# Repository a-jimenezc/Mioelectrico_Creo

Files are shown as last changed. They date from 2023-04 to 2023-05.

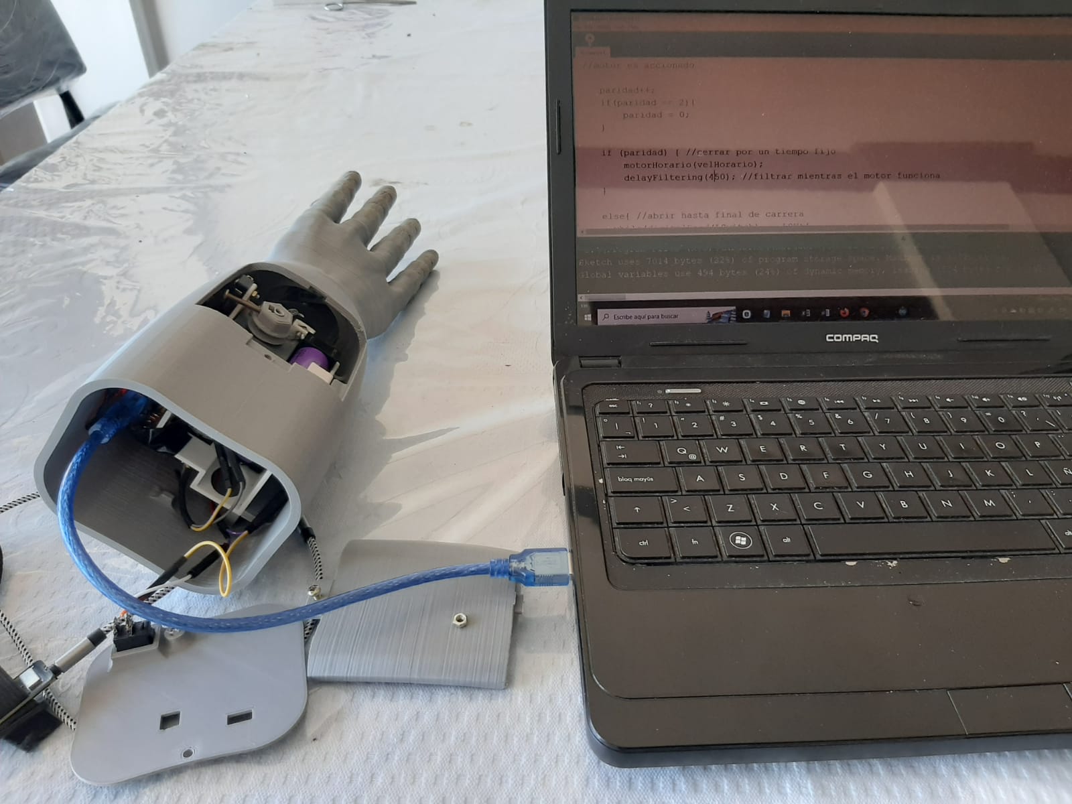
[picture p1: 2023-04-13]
Multimedia/fotos/foto_1.jpeg

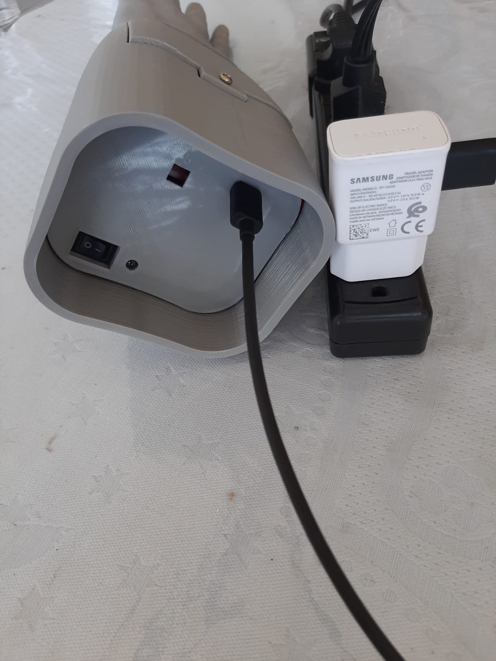
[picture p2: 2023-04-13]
Multimedia/fotos/foto_2.jpeg

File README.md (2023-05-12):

# Proyecto Mioeléctrico

## Descripción
Este proyecto consiste en el desarrollo de una prótesis mioeléctrica para personas con extremidades superiores amputadas. La prótesis utiliza la señal mioeléctrica generada por un músculo para activar un motor que controla la mano de la prótesis. Además, se utiliza una impresora 3D para fabricar las piezas de la prótesis en PLA. 

## Requisitos
- Sensor de señal mioeléctrica DF-Robot
- Microcontrolador Arduino Nano
- Diferentes componenetes electrónicos (ver lista)
- Motor para la mano de la prótesis
- Impresora 3D y material PLA

## Funcionamiento
- El sensor captura la señal mioeléctrica del músculo y la envía al Arduino Nano.
- El Arduino Nano procesa la señal en tiempo real utilizando un algoritmo que incluye un filtro digital y una función de activación.
- La función de activación identifica la orden del usuario para activar la prótesis. La orden se envía mediante una contracción brusca del músculo.
- El motor se controla en lazo abierto, alternando el sentido de giro para abrir y cerrar la mano de la prótesis.
- El movimiento del motor se transmite a la mano de la prótesis mediante un eslabón triangular de transmisión.

## Próximos pasos
Actualmente, se está finalizando el desarrollo de esta segunda versión de la prótesis. Es necesario realizar pruebas en pacientes para evaluar el funcionamiento de la misma en condiciones reales. Adicionalmente, se requiere trabajar en la electrónica y el mecanismo de control de la prótesis. 

Revisar la carpeta documentación para más información.

## Autores
Antonio Jiménez Caballero

Otros autores....

## Licencia
Por definir.

## Contribuciones
Luis Villafani
Otros contribuyentes....

Se aceptan contribuciones al proyecto. Por favor, crea un "pull request" con tus propuestas.

## Contacto
Por definir.

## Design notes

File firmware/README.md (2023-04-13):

## Control Mioeléctrico para Control de Motores utilizando Arduino

Este código de Arduino está diseñado para habilitar el control mioeléctrico de un motor utilizando un sensor EMG analógico. El código utiliza la biblioteca "movingAvg" para calcular promedios móviles y la biblioteca "EMGFilters" para filtrar las señales EMG. El código está destinado a ser utilizado con un sensor EMG analógico, como el sensor "Analog_EMG_Sensor_by_OYMotion_SKU_SEN0240".

Para usar este código, sigue los siguientes pasos:

### Paso 1: Configuración del Hardware

Conecta el sensor EMG analógico a la placa de Arduino. El cable de señal del sensor debe conectarse al pin A7 de Arduino (o cambia el valor de "SensorEmgInputPin" al número de pin apropiado en el código).
Conecta el motor a los pines apropiados de Arduino para el control del motor. El motor se controla mediante señales PWM, así que asegúrate de conectarlo a los pines apropiados con capacidad de PWM (por ejemplo, D9 y D10).

### Paso 2: Configuración del Software

Instala las bibliotecas "movingAvg" y "EMGFilters" en tu entorno de desarrollo de Arduino. Estas bibliotecas son necesarias para que el código funcione correctamente.
Copia y pega el código proporcionado en tu entorno de desarrollo de Arduino.

### Paso 3: Configuración

Configura los parámetros en el código para adaptarlos a tus requisitos específicos. Por ejemplo, puedes ajustar la frecuencia de muestreo, la frecuencia de rechazo, el intervalo de muestreo, los parámetros de control del motor y los valores de umbral según tus necesidades.
Asegúrate de leer y entender la documentación de las bibliotecas "movingAvg" y "EMGFilters" para configurarlas y utilizarlas correctamente en tu código.

### Paso 4: Carga y Ejecución

Carga el código en tu placa de Arduino.
Abre el Monitor Serie en tu entorno de desarrollo de Arduino para ver la salida del código.
Enciende tu motor y tu sensor EMG.
El código realizará el control mioeléctrico del motor basado en las señales EMG filtradas y los valores de umbral calculados durante la ejecución.

Nota: Es importante calibrar adecuadamente los valores de umbral para tu configuración específica para asegurar un control mioeléctrico confiable y preciso del motor. Experimenta con diferentes valores de umbral y parámetros de control del motor para lograr el rendimiento deseado.

Para obtener más información sobre el código, consulta los comentarios en el código y la documentación de las bibliotecas "movingAvg" y "EMGFilters". Además, consulta la documentación del sensor EMG analógico utilizado en tu configuración para obtener más detalles sobre su uso y calibración.

Descargo de responsabilidad: Este código se proporciona tal cual y puede requerir más modificaciones y pruebas para tu aplicación específica. Úsalo bajo tu propio riesgo y siempre sigue las precauciones de seguridad apropiadas al trabajar con motores y circuitos eléctricos.

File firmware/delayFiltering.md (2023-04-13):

La función *delay_filtering* permite leer pulsos enviados por el músculo. Además, permite adaptar en tiempo real el threshold de activación del motor según las amplitud de la señal.

Matemáticamente, la función juega con el delay intrínseco del filtro *moving average* para ser sensible únicamente a los cambios bruscos en la señal. Esto permite que el motor pueda ser controlado con pulsos del músculo, a la vez que se evita el ruido.

    void delayFiltering(int milliseconds){
      int milliseconds_2 = (1000/sample_interval)*milliseconds; //float to int
      for(int i=0; i < milliseconds_2; i++){//delay filtrando
           int Value= analogRead(SensorEmgInputPin);
           int DataAfterFilter = myFilter.update(Value);
           unsigned  long envlope = sq(DataAfterFilter);
           unsigned  long mov_avg = movAvg_myo.reading(envlope);

           if(Threshold < 60){Threshold = aux_trh.reading(trsh_60);} //treshold dinámico
           else if(Threshold < prim_int ){Threshold = aux_trh.reading(mov_avg*(1+(funParametro_1-pow(Threshold,1/30))));}
           else if(Threshold < seg_int ){Threshold = aux_trh.reading(mov_avg*(1+(funParametro_2-pow(Threshold,1/30))));} 
           else{Threshold = aux_trh.reading(mov_avg*(1+(1.2-pow(Threshold,1/30))));}

           Serial.print("absuared Data: ");
           Serial.println(mov_avg);
           Serial.print("threshold: ");
           Serial.println(Threshold);
       delayMicroseconds(sample_interval);//debe coincidir con SAMPLE_FREQ
      }   
    }

Descripción:

La función "delayFiltering" realiza el filtrado de las señales EMG y la actualización del umbral dinámico de manera retardada durante un tiempo especificado en milisegundos. A continuación se describen los pasos principales del proceso:

Conversión de milisegundos a muestras: Se calcula el número de muestras necesarias para el retardo, multiplicando el tiempo en milisegundos por la frecuencia de muestreo inversa en segundos (1000/sample_interval), donde "sample_interval" es el intervalo de muestreo de las señales EMG en microsegundos.

Bucle de filtrado: Se inicia un bucle que se ejecuta tantas veces como el número de muestras calculado en el paso anterior. Dentro del bucle, se realiza lo siguiente:
a. Lectura del valor del sensor EMG: Se lee el valor analógico del pin del sensor EMG utilizando la función "analogRead" y se almacena en la variable "Value".
b. Filtrado de la señal EMG: Se aplica el filtro de EMG previamente configurado utilizando la función "update" de la instancia "myFilter" y se obtiene el valor filtrado en la variable "DataAfterFilter".
c. Cálculo del valor del umbral dinámico: Se calcula el valor del umbral dinámico en función de los parámetros de control y el valor filtrado de la señal EMG. Dependiendo del valor actual del umbral, se utilizan diferentes ecuaciones para calcular el nuevo valor del umbral. Los cálculos se realizan utilizando las funciones "reading" de las instancias "aux_trh", "movAvg_myo" y las operaciones matemáticas como potenciación y raíz. El resultado se almacena en la variable "Threshold".
d. Impresión de valores: Se imprimen en el Monitor Serie los valores del valor absoluto del promedio móvil de la señal EMG (mov_avg) y el umbral dinámico calculado (Threshold) para fines de depuración.
e. Retardo: Se espera un tiempo equivalente al intervalo de muestreo (sample_interval) utilizando la función "delayMicroseconds".

Finalización del bucle: Una vez que se completan todas las iteraciones del bucle, la función "delayFiltering" finaliza.

Es importante tener en cuenta que el valor del umbral dinámico se actualiza en función de los parámetros de control y los valores filtrados de la señal EMG durante el retardo especificado, lo que permite adaptar el umbral a los cambios en la señal EMG en tiempo real.

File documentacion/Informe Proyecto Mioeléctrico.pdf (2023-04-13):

Informe Proyecto Mioeléctrico

Ing. Antonio Jimenez Caballero

### 1. Introducción

Las prótesis funcionales de extremidades superiores presentan una solución para las personas que no disponen de estos miembros. Las prótesis que están siendo actualmente comercializadas en Creotec presentan una construcción mecánica simple pero robusta. La estructura se fabrica con tecnología aditiva y se utiliza un mecanismo de accionamiento que hace uso de hilos, ligas y del principio de palanca. Con esto se logra aprovechar el movimiento de la articulación del codo para lograr abrir y cerrar la mano de la prótesis. Si bien simple y robusta en su construcción, estas prótesis solo pueden ser usadas si es posible hacer uso de la articulación del codo. En los casos donde se tiene el muñón del antebrazo muy pegado al codo o donde solo se disponga del brazo se necesita de otro tipo de prótesis. En este contexto es donde se presenta una prótesis mioeléctrica que hace uso de un motor para accionar la mano de la prótesis. Mediante la lectura de la señal mioeléctrica generada por un músculo, un algoritmo se encarga de activar un motor dc alimentado por baterías el cuál acciona la mano de la prótesis a través de hilos. Adicionalmente, se consigue que el cierre de la mano se adapte a la forma del objeto mediante el uso de un eslabón triangular de transmisión. Actualmente, se está terminando el desarrollo de una segunda versión de esta prótesis mioeléctrica con miras a empezar a hacer pruebas en pacientes.

### 2. Marco teórico

a. Señal electromiografía
Una señal mioeléctrica es la diferencia de potencial generada por los músculos cuando estos se contraen. Las señales EMG tienen una frecuencia que oscila entre 50 y 150 Hz y una amplitud que va desde los μV hasta los 10 mV. Para capturar esta señal se hace uso de electrodos. Estos pueden ser de diversos tipos y el que se utiliza en este proyecto es el electrodo seco de superficie. Estos son electrodos no invasivos que pueden ser montados sobre la misma prótesis y ofrecen la mayor comodidad para su uso continuo. Sin embargo, la calidad de la lectura va a depender del correcto posicionamiento del sensor y de las propiedades conductivas de la piel.

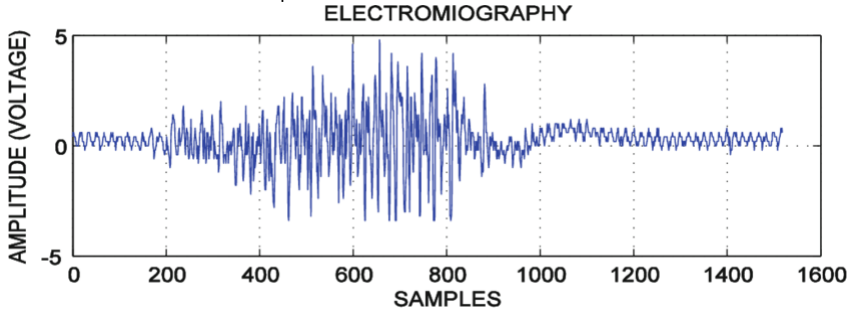
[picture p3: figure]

Figura 1: Señal Mioeléctrica (Vicario)

b. Impresión en 3d
Se utiliza tecnología de fabricación aditiva para la elaboración de la prótesis. En específico, se utiliza modelado por deposición fundida (FDM) de plástico. El plástico utilizado es PLA (poliácido láctico), el cuál es bio-compatible. El uso de esta tecnología permite la fabricación de piezas complejas a bajo costo. Esto es ideal para prótesis personalizadas, cuya fabricación no sería posible mediante otros métodos.

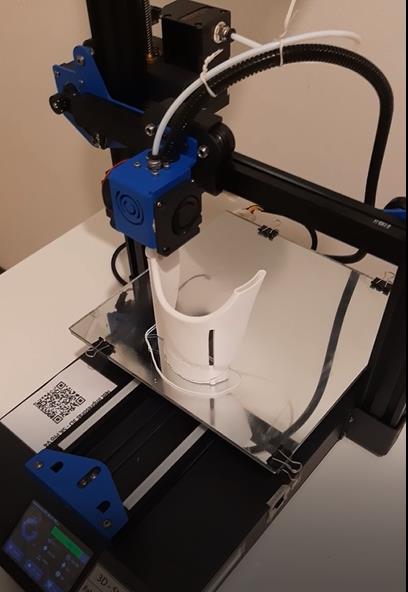
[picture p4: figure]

Figura 2: Impresión de Prótesis

### 3. Prótesis mioeléctrica

La prótesis mioeléctrica que se ha desarrollado hace uso del sensor comercializado por DF-Robot el cual integra un filtro analógico y provee las librerías para un filtro digital

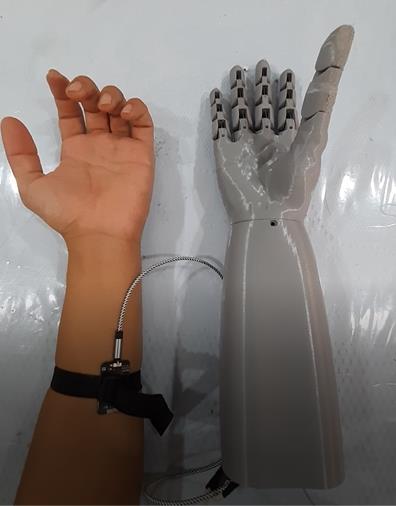
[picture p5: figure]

Figura 3: Prótesis Mioeléctrica

La señal recibida a través de este sensor es enviada al microcontrolador. En este caso se utiliza un ATmega328P el cual viene integrado en el Arduino Nano. El microcontrolador procesa la información recibida en tiempo real mediante la ejecución de un algoritmo. Este consta de un filtro digital, una función de activación y el control del motor. La función de activación es la que permite separar las diferentes señales del músculo de la orden consciente enviada con el propósito de activar la prótesis. La forma en que la prótesis es activada es mediante un pulso de alta intensidad creada por el músculo, el cual se logra mediante una contracción brusca del dicho músculo. La función hace uso de la diferencia del delay de dos filtros de media variable (Moving Average) para capturar la presencia del pulso. Una vez este es identificado se da la orden para que el motor funcione. El sentido de giro del motor alternará entre horario y antihorario con cada orden, lo cual corresponde con abrir y cerrar respectivamente. La orden de cerrar hace que el motor funcione por un tiempo fijo en sentido antihorario y la orden de abrir consiste en el motor funcionando en sentido apuesto hasta topar con un final de carrera, el cual coincide con la posición de mano abierta. Cabe mencionar que este es un mecanismo de control del motor de lazo abierto.

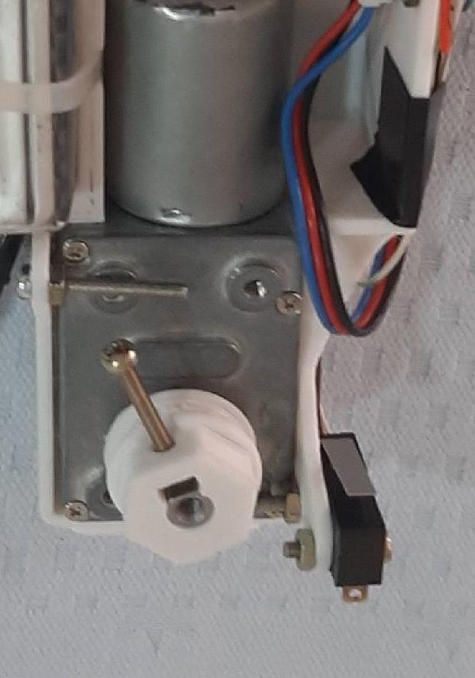
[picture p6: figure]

Figura 4: Motor con el Tambor Unido al eje

El motor acciona el hilo mediante un tambor, el movimiento de este hilo se transmite a otros cinco hilos, uno por dedo, a través de un eslabón triangular. Este eslabón permite que los hilos se deslicen uno respecto del otro, permitiendo que el cierre de los dedos se adapte a la forma del objeto que se está agarrando.

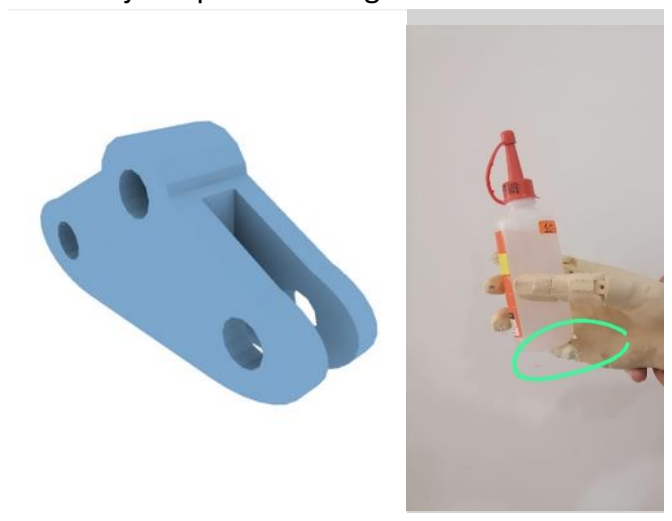
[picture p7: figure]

Figura 5: Eslabón Triangular y Agarre Adaptativo (SkipMeetze)

El motor es alimentado con un par de baterías Li-ion 18650 dispuestas en paralelo. Junto con las baterías se tiene sus protecciones (BMS), su módulo de carga (micro-USB) y su elevador de tensión (Step-Up).

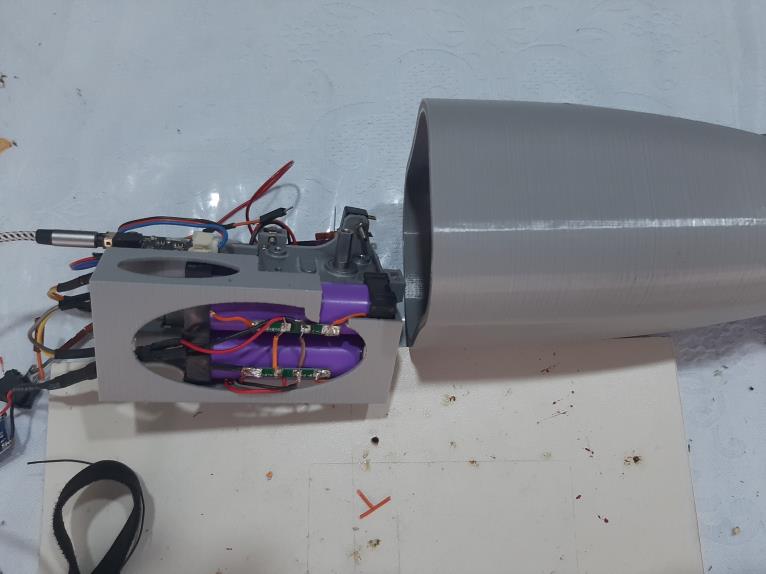
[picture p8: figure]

Figura 6: Baterías en la Estructura Extraíble

Todos los componentes están dispuestos en un chasis extraíble, lo cual permite que toda la electrónica pueda ser ensamblado fuera de la prótesis. Una vez todo este en su lugar, esta es introducida en el interior de la prótesis y se procede a ajustar la tensión del hilo principal a través de una abertura dejada para tal propósito.

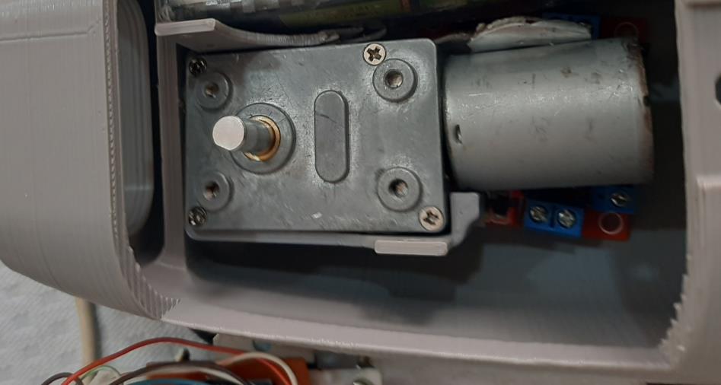
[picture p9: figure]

Figura 7: Estructura Extraíble Instalada en el Antebrazo

### 4. Conclusiones

La prótesis mioeléctrica presentada puede ser usada por personas que no presenten la articulación del codo y, por lo tanto, se presenta como una solución al problema planteado. Al usar elementos electrónicos de uso común y disponibles para su compra en Bolivia, esta puede ser construida a muy bajo costo comparada con otras prótesis comerciales de su tipo. Sin embargo, se pueden evidenciar mejoras a realizar. La primera es la posibilidad de extraer más información de la señal del sensor mioeléctrico. Esto se puede realizar mediante el uso de técnicas de procesamiento digital de señales para extraer características de la señal y lograr más estados que solo abrir o cerrar. En particular, se desea que la intensidad del cierre se proporcional a la intensidad de la acción del músculo, esto con el fin de dar mayor control a la persona sobre los objetos que se están agarrando. Un segundo elemento a mejorar el añadir un control de lazo cerrado al motor. Esto permitiría mayor precisión en el agarre de objetos. Un tercer elemento a mejorar es la implementación de un PCB que integre toda la electrónica. Si bien el uso de módulos electrónicos comerciales es ventajoso en términos de hacer prototipos, el elevado volumen de cables es un problema. Finalmente, es necesario estudiar el lugar idóneo para posicionar el sensor, ya que estos deber ir sobre músculos óptimos para la tarea.

### 5. Referencias

SkipMeetze. Adaptive grip mechanism for Prosthetic hand. National Institutes of Health. Retrieved October 24, 2022, from https://3dprint.nih.gov/discover/3dpx-001001

Vicario Vazquez, S. A., Oubram, O., &amp; Ali, B. (2018). Intelligent recognition system of myoelectric signals of Human Hand Movement. Intelligent Computing Systems, 97–112. https://doi.org/10.1007/978-3-319-76261-6_8

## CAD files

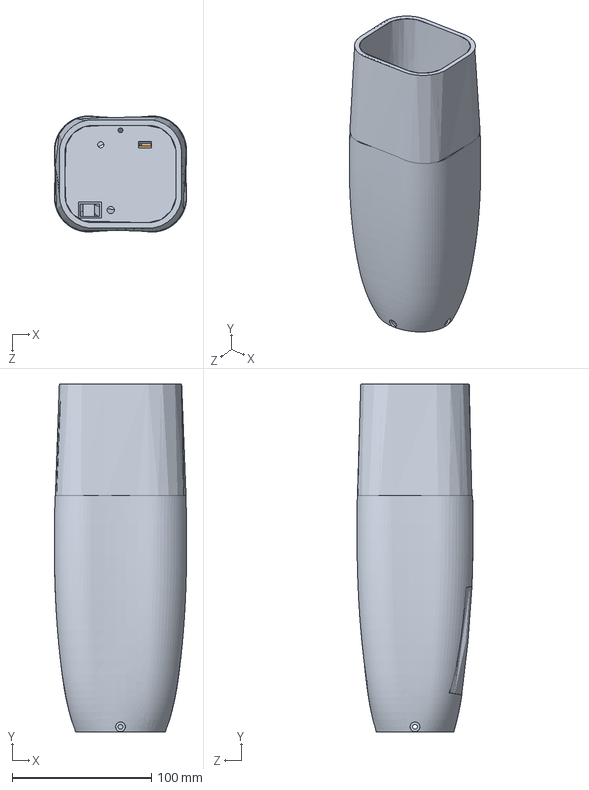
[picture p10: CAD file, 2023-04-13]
SW_CAD_files/AssemV6/Assem1.SLDASM
95.2 x 250.2 x 83.5 mm
AntebrazoV6
chasis3V1
switchV2

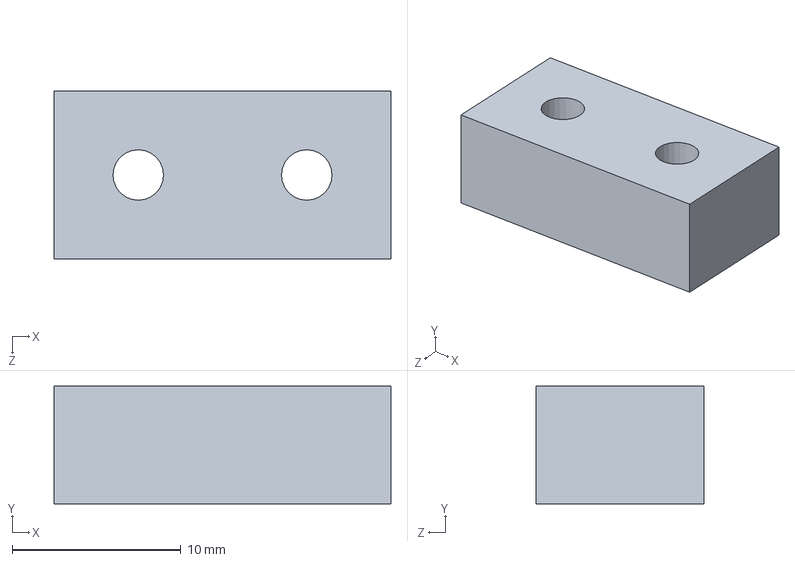
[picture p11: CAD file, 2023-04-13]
SW_CAD_files/AssemV6/switchV2.SLDPRT
20.0 x 7.00 x 10.0 mm

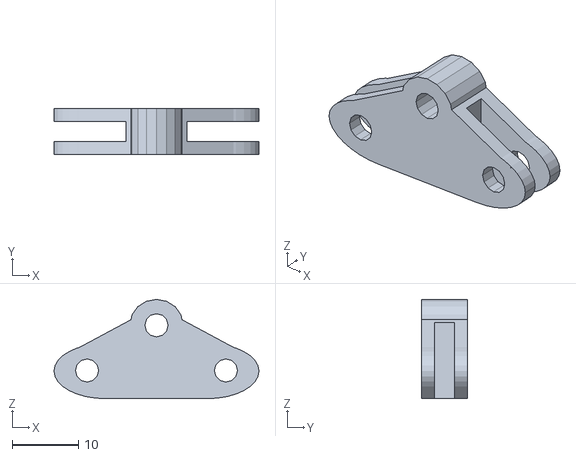
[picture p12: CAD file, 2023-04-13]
SW_CAD_files/eslabon_adaptativo.stl
31.0 x 7.00 x 15.0

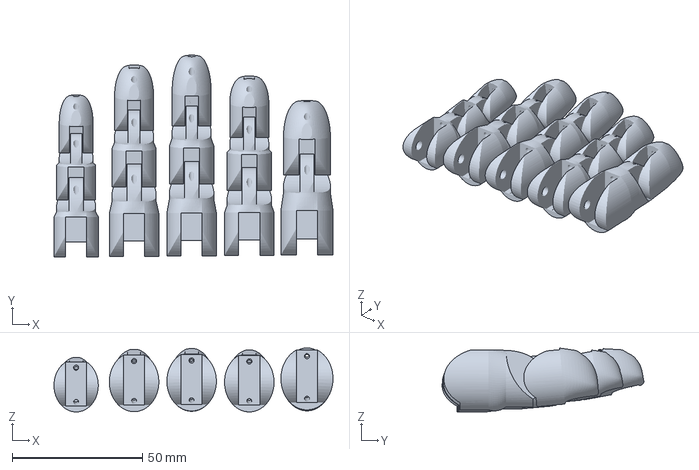
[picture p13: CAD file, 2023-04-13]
SW_CAD_files/Mano/Dedos.3mf
107.1 x 77.4 x 24.6 mm

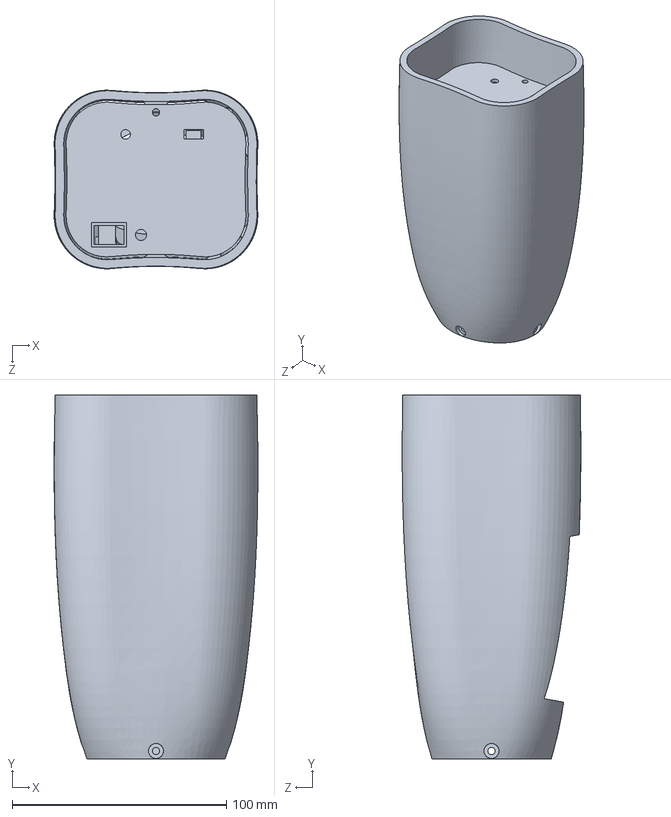
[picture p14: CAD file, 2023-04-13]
SW_CAD_files/AssemV6/AntebrazoV6.SLDPRT
95.2 x 170.0 x 83.5 mm

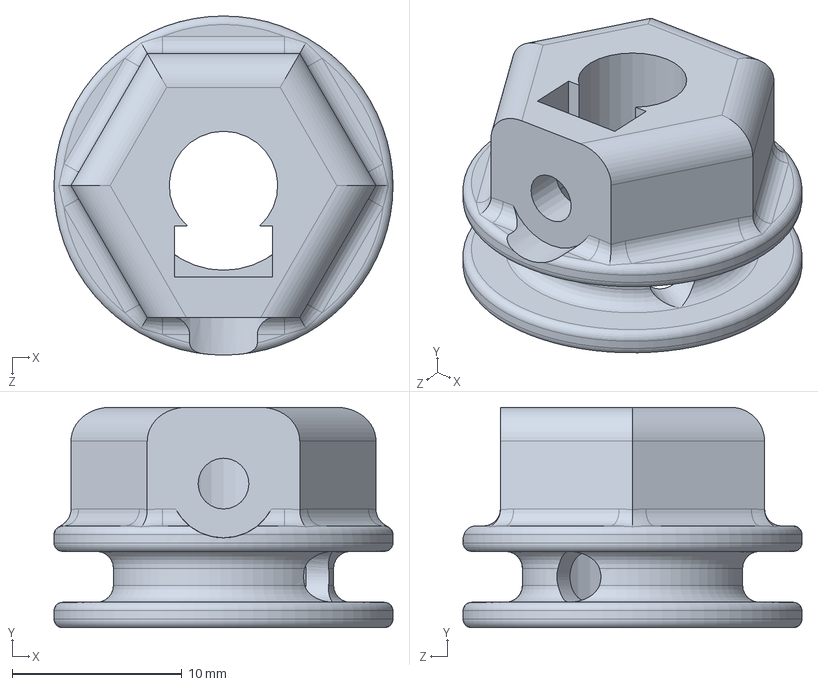
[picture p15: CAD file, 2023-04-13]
SW_CAD_files/tambor_motor.SLDPRT
20.0 x 13.0 x 20.0 mm

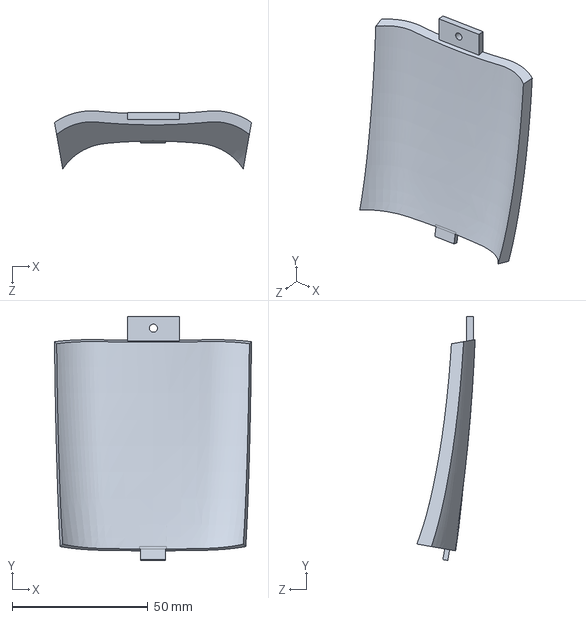
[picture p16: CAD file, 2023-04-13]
SW_CAD_files/AssemV6/tapa.SLDPRT
72.5 x 89.8 x 21.5 mm

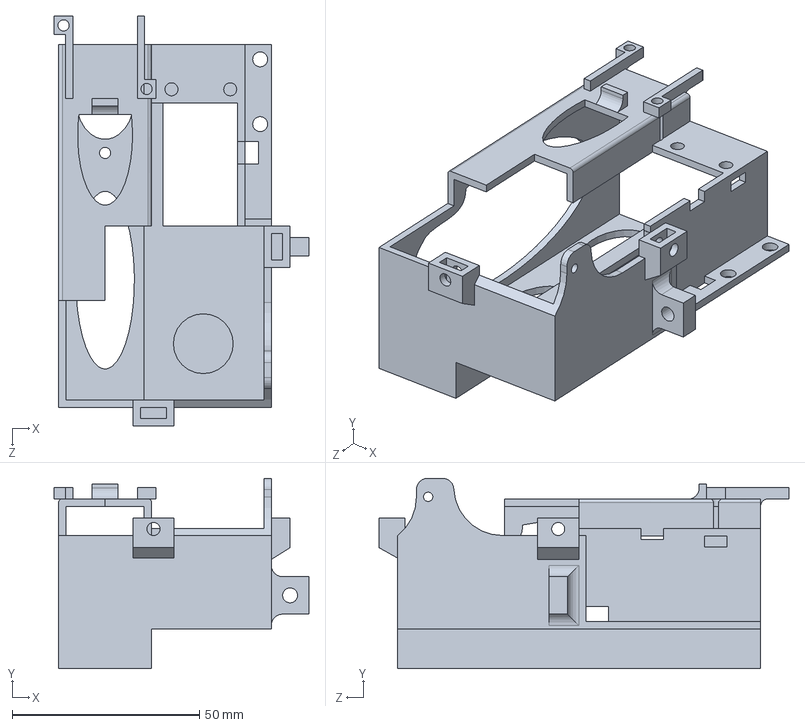
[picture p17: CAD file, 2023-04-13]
SW_CAD_files/AssemV6/chasis3V1.SLDPRT
68.0 x 50.9 x 109.6 mm

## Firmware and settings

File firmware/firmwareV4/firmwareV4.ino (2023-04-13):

/*promediar sensor myo y el threshold, libreria movingAvg
    docuentación: https://www.arduino.cc/reference/en/libraries/movingavg/ 
 *Para mas información sobre el codigo del sensor myo ir a 
 *  https://wiki.dfrobot.com/Analog_EMG_Sensor_by_OYMotion_SKU_SEN0240 */

#include <movingAvg.h> 
#include "Arduino.h"
#include "EMGFilters.h"

#define SensorEmgInputPin A7 // input pin number
#define LSwitch 2 //switch input pin


EMGFilters myFilter; //filtro del mioeléctrico
// our emg filter only support "SAMPLE_FREQ_500HZ" or "SAMPLE_FREQ_1000HZ"
// other sampleRate inputs will bypass all the EMG_FILTER
enum SAMPLE_FREQUENCY sampleRate = SAMPLE_FREQ_500HZ;
enum NOTCH_FREQUENCY humFreq = NOTCH_FREQ_50HZ;

int sample_interval = 500; //microseconds. sample_interval debe coincidir con la frequencia de muestreo del filtro

int velHorario = 255;
int velAntihorario = 255;

int paridad = 0;
int start = 1;
unsigned long Threshold = 0;

//variables para el treshold dinámico
int inercia_senal = 30; //inercia señal original ----------------
int inercia_trsh =  10; //inercia del threshold ------------

int trsh_60 = 80; //threshold fijo para valores debajo de 60

int prim_int = 800; //limite del primer intervalo 
double funParametro_1 = 1.3; //modifica la altura del threshold para valores < 800 --------

int seg_int = 2000; //limite del segundo intervalo 
double funParametro_2 =1.2; //modifica la altura del threshold para valores <2000 ---------
 
//inicializar moving average
movingAvg movAvg_myo(inercia_senal);
movingAvg aux_trh(inercia_trsh);

void delayFiltering(int milliseconds){
  int milliseconds_2 = (1000/sample_interval)*milliseconds; //float to int
  for(int i=0; i < milliseconds_2; i++){//delay filtrando
       int Value= analogRead(SensorEmgInputPin);
       int DataAfterFilter = myFilter.update(Value);
       unsigned  long envlope = sq(DataAfterFilter);
       unsigned  long mov_avg = movAvg_myo.reading(envlope);

       if(Threshold < 60){Threshold = aux_trh.reading(trsh_60);} //treshold dinámico
       else if(Threshold < prim_int ){Threshold = aux_trh.reading(mov_avg*(1+(funParametro_1-pow(Threshold,1/30))));}
       else if(Threshold < seg_int ){Threshold = aux_trh.reading(mov_avg*(1+(funParametro_2-pow(Threshold,1/30))));} 
       else{Threshold = aux_trh.reading(mov_avg*(1+(1.2-pow(Threshold,1/30))));}

       Serial.print("absuared Data: ");
       Serial.println(mov_avg);
       Serial.print("threshold: ");
       Serial.println(Threshold);
       delayMicroseconds(sample_interval);//debe coincidir con SAMPLE_FREQ
  }   
}


void motorAntihorario(int velAntihorario){
  digitalWrite(9, LOW); 
  analogWrite(10, velAntihorario);
  }

void motorHorario(int velHorario){
  digitalWrite(10, LOW);
  analogWrite(9, velHorario);
}

void motorApagar(){
  digitalWrite(9, LOW);
  digitalWrite(10, LOW);
}


float fmap(float x, float in_min, float in_max, float out_min, float out_max)
{   return (x - in_min) * (out_max - out_min) / (in_max - in_min) + out_min;}

void setup() {
  
  Serial.begin(115200);
  
  myFilter.init(sampleRate, humFreq, true, true, true);
  movAvg_myo.begin();
  aux_trh.begin(); 

  pinMode(9,OUTPUT);  //motor 1 pwmD9 
  pinMode(10,OUTPUT);  //motor 1 pwmD10 
  pinMode(LSwitch, INPUT); //Final de carrera

}

void loop() {

    if(start){ //configuración inicial
      delayFiltering(500);
      start = 0;
    }
      
    // proceso de filtrado
    int Value= analogRead(SensorEmgInputPin);
    int DataAfterFilter = myFilter.update(Value);
    unsigned  long envlope = sq(DataAfterFilter);
    unsigned  long mov_avg = movAvg_myo.reading(envlope);

    if(Threshold < 60){Threshold = aux_trh.reading(trsh_60);} //treshold dinámico
    else if(Threshold < prim_int ){Threshold = aux_trh.reading(mov_avg*(1+(funParametro_1-pow(Threshold,1/30))));}
    else if(Threshold < seg_int ){Threshold = aux_trh.reading(mov_avg*(1+(funParametro_2-pow(Threshold,1/30))));} 
    else{Threshold = aux_trh.reading(mov_avg*(1+(1.2-pow(Threshold,1/30))));}
    delayMicroseconds(sample_interval); 

    Serial.print("absuared Data: ");
    Serial.println(mov_avg);
    Serial.print("threshold: ");
    Serial.println(Threshold);

    if(mov_avg > 10000){return;} //eliminar picos
    if(mov_avg < Threshold){ return;} //el motor no es accionado         
      
 //motor es accionado

    paridad++;
    if(paridad == 2){
        paridad = 0;      
    }

    if (paridad) { //cerrar por un tiempo fijo
        motorHorario(velHorario);
        delayFiltering(450); //filtrar mientras el motor funciona
    } 
      
    else{ //abrir hasta final de carrera
      while(digitalRead(LSwitch) == LOW){
          motorAntihorario(velAntihorario);
          delayFiltering(2);//mayor que 2
      }
      while(digitalRead(LSwitch) == HIGH){
          motorHorario(velHorario);
          delayFiltering(2);//mayor que 2
      }
    }       
    motorApagar(); 
    delayFiltering(300);        
}
